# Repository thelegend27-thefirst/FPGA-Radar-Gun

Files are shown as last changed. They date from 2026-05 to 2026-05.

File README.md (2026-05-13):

# FPGA-Radar-Gun
FPGA Radar Gun project using a HB100 Doppler Radar Module 0~2mph

This project uses the HB100 Doppler Module to track speeds of different objects and displays it on the 7 segment display of the Nexys A7 FPGA board. To run the code simply clone the repo, open the xpr file, make sure top module is selected as top, and generate bitstream. After you have flashed the bitstream the Nexys A7 FPGA, build the circuit provided in the README system architecture section. You will need op-amps (I used MCP6002, but any op-amp works), resistors, and capacitors (electrolytic and ceramic). Connect the output of the circuit to JD1 of the FPGA. Also connect gnd of circuit to gnd of pmod JD. You can use the 3D printed chasis I have provided, though you will need double-sided tape for the HB100 to mount it and the FPGA board to make it stay still. 

# Project Overview
This project uses the HB100 Doppler Module. The module sends out radio waves and receives them. Due to the doppler effect, the radio waves sent back will have a shift in frequency. The module will output that change in frequency as an analog signal. The analog signal will then go through a circuit that will amplify it and convert it from analog to digital. It will then go into the FPGA board which will measure the frequency of the input signal and use a formula to calculate speed. The speed will be displayed on the 7 segment display. 

# System Architecture 

The output of the HB100 is a tiny analog signal (mV~uV) at a certain frequency. That frequency is the doppler effect frequency and exactly what we need to input into our formula. The output is so small and the FPGA can not read it. We will need to amplify it with a circuit. Here is how the circuit works. The analog signal first goes through a capacitor which filters out any DC offset from the HB100 because we only care about the AC part of the signal (1). Then we introduce a voltage divider to set a midpoint at 1.65v (3.3v/2). The midpoint is used because everything above the midpoint will be considered “high” and everything below will be “low” (2). After that our signal goes through a non-inveriting op amp which amplifies the signal 100x (3). Then a second non-inverting op amp turns the signal into a complete square wave (4). In the end we have a square wave at a frequency that is equivalent to the frequency of the doppler effect. Now we have to measure the frequency of the square wave which will be done inside the FPGA. 
Note: I did not end up use a decoupling capacitor on the HB100 as the vcc & gnd pins were too far apart

# Interfaces & Peripherals Used

To measure frequency the strategy I implemented was using a timer to count to the time between rising edges then using the formula f=1/T to measure frequency. I implemented a timer using the internal 100Mhz clk of the FPGA board. I used a loop so that at every posedge of the clk, I’d increment a counter by 1. This counter just counts. I then used another loop where at every posedge of the input signal, the counter would start, wait for the next posedge, stop, and output the count. Now what we have to do is multiply this count by .0000001 as each posedge of the clk is equal to .0000001s or 10 nano seconds. Then I divided 1 by the count to get frequency. However, this process simplifies to 100Mhz / count, so that is what I ended up using to get frequency. 

To convert frequency to speed the formula v=f*lamda/2. Lamda is the wavelength of the original wave, it is found using lamda=vf where v is equal to the speed of light. It varies across radar guns, our HB100 operates at 10.525 GHz and therefore lamda = .0285 in our case. A problem I faced was that the FPGA can not do floats so I had to modify the formula. I just ended up doing all the calculations with a decimal point over. For example a speed of 12.5 will be calculated as 125. Which is fine because we actually need it in this form for the 7 segment display later. The modified equation I used is v=(f  * 285) + 10002000. The +1000 is there because the FPGA always rounds down, so +1000 ensures proper rounding. I then used v=(v * 2237) + 5001000 to convert m/s to mph (m/s * 2.23694 = mph). It uses the same modifications as the first formula for the same reasons. Here is a table to show conversion from frequency to speed so you get an idea.

Frequency (Hz)     Speed (mph)
10                  0.32
20                  0.64
30                  0.96
1600                51.04

Once we had our speed we needed to display onto the 7 segment display. However the 7 segment display on the Nexys A7 FPGA board only has one set of cathodes connected to all 8 anodes. This means that one number will display on all of the 7 segments and you can’t send different numbers to different 7 segments. To display a 3 digit speed, I needed to implement multiplexing on the 7 segment display.  What we do is we take our first digit, turn off all the anodes except for one, and display that digit. Then we take the next digit, turn off all the anodes except for the next anode, and display the second digit. Same thing for the 3rd digit. The FPGA board does this so fast that it looks like all 3 digits are being displayed at the same time and you can see a clear speed. 

# Verification & Testing

For verification I did both software and hardware verification. For software verification I simulated different input frequencies being imputed into the FPGA board. I did it by creating a testbench and toggling the input at a fixed rate. To find how often I need to toggle, I would take the frequency I want to simulate input it into T=1f. This would give us the time for one period, then I would divide that by 2 to get the toggle delay. 

I noticed that during transitions, the FPGA would output speeds in between 2 frequencies. This is because it would read the rising edge of one frequency than read the rising edge of a different frequency, resulting in a speed in between. This was fine though as it just showed acceleration and deceleration. Note that speeds on waveform are 1 magnitude lower than displayed i.e. 320 = 32.0mph.

For hardware verification I did physical testing with the FPGA board, circuit, and module. I made all the connections using a breadboard and began rolling objects in front of the HB100. Something that I found really helpful was using an oscilloscope. The oscilloscope would display what’s happening with the signal and was very helpful with debugging. You can also see on the oscilloscope our circuit amplification as it takes a tiny signal in mV and amplifies it to a 3.3v square wave.





# Conclusion
In this project, I successfully designed and implemented an FPGA-based radar speedometer using the HB100 Doppler module. The system was able to detect motion, process the resulting Doppler frequency shift, and convert it into a readable speed displayed on a 7-segment display. This required integrating analog signal conditioning, digital frequency measurement, and hardware-based computation on the FPGA. Through both simulation and hardware testing, I verified that my design functioned as intended.
However, the overall performance of the system was limited by the HB100 module. The maximum output frequency observed was significantly lower than expected, restricting measurable speeds to approximately 0–2 mph. While the signal processing and FPGA implementation were correct, this hardware limitation prevented the system from being used for higher-speed applications such as vehicle detection.
In future work, this limitation could be addressed by selecting a Doppler module with a higher output frequency range or by improving the sensitivity and amplification stages of the circuit. Additionally, implementing more advanced signal processing techniques or filtering could improve accuracy and noise resilience. Despite its limitations, this project provided valuable experience in combining analog and digital design, working with real-world signals, and implementing mathematical models on FPGA hardware.



# Demos
https://www.youtube.com/watch?v=i8uyQCpuomU

https://www.youtube.com/watch?v=ts4kDAqrsdw

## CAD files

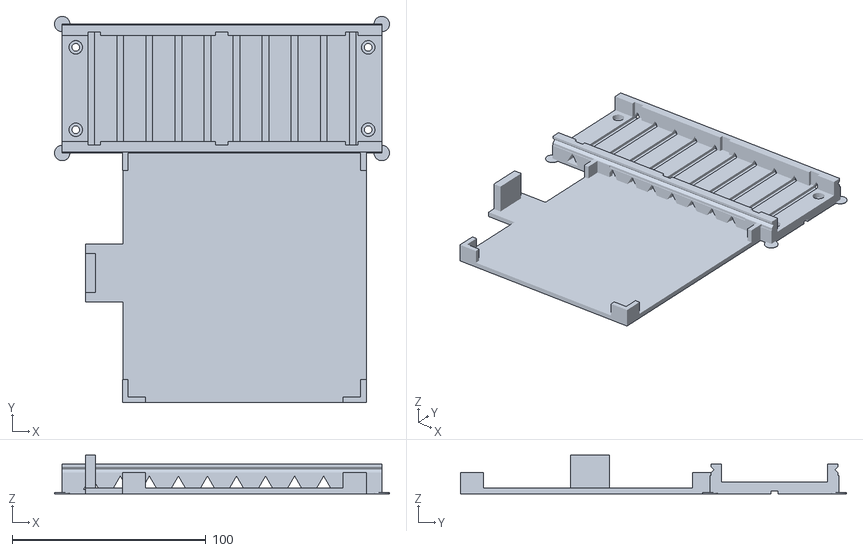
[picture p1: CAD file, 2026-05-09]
Nexys A7 FPGA & Breadboard (3).stl
173.1 x 199.6 x 20.0

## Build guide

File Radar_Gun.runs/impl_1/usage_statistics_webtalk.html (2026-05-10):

### Device Usage Page (usage_statistics_webtalk.html)

This HTML page displays the device usage statistics that will be sent to Xilinx.
To see the actual file transmitted to Xilinx, please click here.

software_version_and_target_device
beta | FALSE | build_version | 2708876
date_generated | Mon May 4 16:14:32 2026 | os_platform | WIN64
product_version | Vivado v2019.2 (64-bit) | project_id | d7756ef397354c6abce82c2c75414546
project_iteration | 7 | random_id | 1eeea3ededb85181a77914f9714619ef
registration_id | 1eeea3ededb85181a77914f9714619ef | route_design | TRUE
target_device | xc7a100t | target_family | artix7
target_package | csg324 | target_speed | -1
tool_flow | Vivado

user_environment
cpu_name | AMD Ryzen 7 7735HS with Radeon Graphics | cpu_speed | 3194 MHz
os_name | Windows Server 2016 or Windows 10 | os_release | major release (build 9200)
system_ram | 14.000 GB | total_processors | 1

vivado_usage

gui_handlers
addsrcwizard_specify_hdl_netlist_block_design=3 | addsrcwizard_specify_or_create_constraint_files=2 | addsrcwizard_specify_simulation_specific_hdl_files=1 | basedialog_cancel=11
basedialog_no=1 | basedialog_ok=46 | basedialog_yes=13 | closeplanner_no=1
cmdmsgdialog_ok=22 | commandsinput_type_tcl_command_here=1 | constraintschooserpanel_add_files=1 | constraintschooserpanel_create_file=3
constraintschooserpanel_file_table=1 | createconstraintsfilepanel_file_name=2 | createsrcfiledialog_file_name=8 | filesetpanel_file_set_panel_tree=228
flownavigatortreepanel_flow_navigator_tree=106 | graphicalview_zoom_fit=39 | hcodeeditor_search_text_combo_box=2 | logmonitor_monitor=1
logpanel_pause_output=4 | mainmenumgr_file=6 | mainmenumgr_project=6 | msgtreepanel_message_view_tree=18
pacommandnames_add_sources=11 | pacommandnames_auto_connect_target=6 | pacommandnames_auto_update_hier=45 | pacommandnames_edit_constraint_sets=1
pacommandnames_edit_simulation_sets=1 | pacommandnames_make_active_cnsset=6 | pacommandnames_open_hardware_manager=2 | pacommandnames_open_project=3
pacommandnames_set_as_top=7 | pacommandnames_set_target_ucf=4 | pacommandnames_set_used_in_prop=1 | pacommandnames_simulation_live_run_all=20
pacommandnames_simulation_run_behavioral=36 | pacommandnames_src_disable=3 | pacommandnames_src_enable=1 | paviews_code=4
paviews_project_summary=42 | paviews_schematic=1 | programdebugtab_open_target=7 | programdebugtab_program_device=12
programfpgadialog_program=16 | programfpgadialog_specify_bitstream_file=1 | rdicommands_copy=1 | rdicommands_delete=2
rdicommands_properties=1 | rdicommands_redo=4 | rdicommands_undo=9 | rdiviews_waveform_viewer=170
saveprojectutils_cancel=1 | saveprojectutils_dont_save=1 | saveprojectutils_save=2 | srcchooserpanel_create_file=8
srcfileproppanels_enabled=1 | srcmenu_ip_hierarchy=48 | srcmenu_refresh_hierarchy=1 | srcmenu_set_file_type=3
syntheticagettingstartedview_recent_projects=3 | taskbanner_close=1 | waveformnametree_waveform_name_tree=68 | waveformview_add_marker=3
waveformview_goto_cursor=13 | waveformview_goto_last_time=4 | waveformview_goto_time_0=1 | waveformview_next_marker=2
waveformview_next_transition=5 | waveformview_previous_marker=1

java_command_handlers
addsources=11 | autoconnecttarget=6 | editconstraintsets=1 | editdelete=2
editproperties=1 | editsimulationsets=1 | launchprogramfpga=14 | openhardwaremanager=6
openproject=3 | programdevice=2 | runbitgen=16 | runimplementation=1
runschematic=1 | savefileproxyhandler=2 | setsourceenabled=5 | settargetconstrfile=2
settopnode=6 | showview=7 | simulationrun=35 | simulationrunall=20
viewtaskimplementation=1 | viewtaskprojectmanager=19

other_data

guimode=12

project_data
constraintsetcount=2 | core_container=false | currentimplrun=impl_1 | currentsynthesisrun=synth_1
default_library=xil_defaultlib | designmode=RTL | export_simulation_activehdl=0 | export_simulation_ies=0
export_simulation_modelsim=0 | export_simulation_questa=0 | export_simulation_riviera=0 | export_simulation_vcs=0
export_simulation_xsim=0 | implstrategy=Vivado Implementation Defaults | launch_simulation_activehdl=0 | launch_simulation_ies=0
launch_simulation_modelsim=0 | launch_simulation_questa=0 | launch_simulation_riviera=0 | launch_simulation_vcs=0
launch_simulation_xsim=57 | simulator_language=Mixed | srcsetcount=6 | synthesisstrategy=Vivado Synthesis Defaults
target_language=Verilog | target_simulator=XSim | totalimplruns=1 | totalsynthesisruns=1

unisim_transformation

post_unisim_transformation
bufg=1 | carry4=304 | dsp48e1=2 | fdce=65
fdre=17 | gnd=4 | ibuf=3 | lut1=70
lut2=139 | lut3=924 | lut4=60 | lut5=53
lut6=105 | obuf=16 | vcc=3

pre_unisim_transformation
bufg=1 | carry4=304 | dsp48e1=2 | fdce=65
fdre=17 | gnd=4 | ibuf=3 | lut1=70
lut2=139 | lut3=924 | lut4=60 | lut5=53
lut6=105 | obuf=16 | vcc=3

phys_opt_design_post_place

command_line_options
-aggressive_hold_fix=default::[not_specified] | -bram_register_opt=default::[not_specified] | -clock_opt=default::[not_specified] | -critical_cell_opt=default::[not_specified]
-critical_pin_opt=default::[not_specified] | -directive=default::[not_specified] | -dsp_register_opt=default::[not_specified] | -effort_level=default::[not_specified]
-fanout_opt=default::[not_specified] | -hold_fix=default::[not_specified] | -insert_negative_edge_ffs=default::[not_specified] | -multi_clock_opt=default::[not_specified]
-placement_opt=default::[not_specified] | -restruct_opt=default::[not_specified] | -retime=default::[not_specified] | -rewire=default::[not_specified]
-shift_register_opt=default::[not_specified] | -uram_register_opt=default::[not_specified] | -verbose=default::[not_specified] | -vhfn=default::[not_specified]

report_drc

command_line_options
-append=default::[not_specified] | -checks=default::[not_specified] | -fail_on=default::[not_specified] | -force=default::[not_specified]
-format=default::[not_specified] | -internal=default::[not_specified] | -internal_only=default::[not_specified] | -messages=default::[not_specified]
-name=default::[not_specified] | -no_waivers=default::[not_specified] | -return_string=default::[not_specified] | -ruledecks=default::[not_specified]
-upgrade_cw=default::[not_specified] | -waived=default::[not_specified]

results
cfgbvs-1=1 | dpip-1=2 | dpop-1=2 | dpop-2=2

report_methodology

command_line_options
-append=default::[not_specified] | -checks=default::[not_specified] | -fail_on=default::[not_specified] | -force=default::[not_specified]
-format=default::[not_specified] | -messages=default::[not_specified] | -name=default::[not_specified] | -return_string=default::[not_specified]
-slack_lesser_than=default::[not_specified] | -waived=default::[not_specified]

results

timing-18=18

report_power

command_line_options
-advisory=default::[not_specified] | -append=default::[not_specified] | -file=[specified] | -format=default::text
-hier=default::power | -hierarchical_depth=default::4 | -l=default::[not_specified] | -name=default::[not_specified]
-no_propagation=default::[not_specified] | -return_string=default::[not_specified] | -rpx=[specified] | -verbose=default::[not_specified]
-vid=default::[not_specified] | -xpe=default::[not_specified]

usage
airflow=250 (LFM) | ambient_temp=25.0 (C) | bi-dir_toggle=12.500000 | bidir_output_enable=1.000000
board_layers=12to15 (12 to 15 Layers) | board_selection=medium (10"x10") | clocks=0.000883 | confidence_level_clock_activity=High
confidence_level_design_state=High | confidence_level_device_models=High | confidence_level_internal_activity=Medium | confidence_level_io_activity=Medium
confidence_level_overall=Medium | customer=TBD | customer_class=TBD | devstatic=0.097227
die=xc7a100tcsg324-1 | dsp=0.002078 | dsp_output_toggle=12.500000 | dynamic=0.052287
effective_thetaja=4.6 | enable_probability=0.990000 | family=artix7 | ff_toggle=12.500000
flow_state=routed | heatsink=medium (Medium Profile) | i/o=0.018981 | input_toggle=12.500000
junction_temp=25.7 (C) | logic=0.016251 | mgtavcc_dynamic_current=0.000000 | mgtavcc_static_current=0.000000
mgtavcc_total_current=0.000000 | mgtavcc_voltage=1.000000 | mgtavtt_dynamic_current=0.000000 | mgtavtt_static_current=0.000000
mgtavtt_total_current=0.000000 | mgtavtt_voltage=1.200000 | netlist_net_matched=NA | off-chip_power=0.000000
on-chip_power=0.149515 | output_enable=1.000000 | output_load=5.000000 | output_toggle=12.500000
package=csg324 | pct_clock_constrained=2.000000 | pct_inputs_defined=33 | platform=nt64
process=typical | ram_enable=50.000000 | ram_write=50.000000 | read_saif=False
set/reset_probability=0.000000 | signal_rate=False | signals=0.014094 | simulation_file=None
speedgrade=-1 | static_prob=False | temp_grade=commercial | thetajb=5.7 (C/W)
thetasa=4.6 (C/W) | toggle_rate=False | user_board_temp=25.0 (C) | user_effective_thetaja=4.6
user_junc_temp=25.7 (C) | user_thetajb=5.7 (C/W) | user_thetasa=4.6 (C/W) | vccadc_dynamic_current=0.000000
vccadc_static_current=0.020000 | vccadc_total_current=0.020000 | vccadc_voltage=1.800000 | vccaux_dynamic_current=0.000693
vccaux_io_dynamic_current=0.000000 | vccaux_io_static_current=0.000000 | vccaux_io_total_current=0.000000 | vccaux_io_voltage=1.800000
vccaux_static_current=0.018150 | vccaux_total_current=0.018843 | vccaux_voltage=1.800000 | vccbram_dynamic_current=0.000000
vccbram_static_current=0.000247 | vccbram_total_current=0.000247 | vccbram_voltage=1.000000 | vccint_dynamic_current=0.033374
vccint_static_current=0.015109 | vccint_total_current=0.048484 | vccint_voltage=1.000000 | vcco12_dynamic_current=0.000000
vcco12_static_current=0.000000 | vcco12_total_current=0.000000 | vcco12_voltage=1.200000 | vcco135_dynamic_current=0.000000
vcco135_static_current=0.000000 | vcco135_total_current=0.000000 | vcco135_voltage=1.350000 | vcco15_dynamic_current=0.000000
vcco15_static_current=0.000000 | vcco15_total_current=0.000000 | vcco15_voltage=1.500000 | vcco18_dynamic_current=0.000000
vcco18_static_current=0.000000 | vcco18_total_current=0.000000 | vcco18_voltage=1.800000 | vcco25_dynamic_current=0.000000
vcco25_static_current=0.000000 | vcco25_total_current=0.000000 | vcco25_voltage=2.500000 | vcco33_dynamic_current=0.005353
vcco33_static_current=0.004000 | vcco33_total_current=0.009353 | vcco33_voltage=3.300000 | version=2019.2

report_utilization

clocking
bufgctrl_available=32 | bufgctrl_fixed=0 | bufgctrl_used=1 | bufgctrl_util_percentage=3.13
bufhce_available=96 | bufhce_fixed=0 | bufhce_used=0 | bufhce_util_percentage=0.00
bufio_available=24 | bufio_fixed=0 | bufio_used=0 | bufio_util_percentage=0.00
bufmrce_available=12 | bufmrce_fixed=0 | bufmrce_used=0 | bufmrce_util_percentage=0.00
bufr_available=24 | bufr_fixed=0 | bufr_used=0 | bufr_util_percentage=0.00
mmcme2_adv_available=6 | mmcme2_adv_fixed=0 | mmcme2_adv_used=0 | mmcme2_adv_util_percentage=0.00
plle2_adv_available=6 | plle2_adv_fixed=0 | plle2_adv_used=0 | plle2_adv_util_percentage=0.00

dsp
dsp48e1_only_used=2 | dsps_available=240 | dsps_fixed=0 | dsps_used=2

dsps_util_percentage=0.83

io_standard
blvds_25=0 | diff_hstl_i=0 | diff_hstl_i_18=0 | diff_hstl_ii=0
diff_hstl_ii_18=0 | diff_hsul_12=0 | diff_mobile_ddr=0 | diff_sstl135=0
diff_sstl135_r=0 | diff_sstl15=0 | diff_sstl15_r=0 | diff_sstl18_i=0
diff_sstl18_ii=0 | hstl_i=0 | hstl_i_18=0 | hstl_ii=0
hstl_ii_18=0 | hsul_12=0 | lvcmos12=0 | lvcmos15=0
lvcmos18=0 | lvcmos25=0 | lvcmos33=1 | lvds_25=0
lvttl=0 | mini_lvds_25=0 | mobile_ddr=0 | pci33_3=0
ppds_25=0 | rsds_25=0 | sstl135=0 | sstl135_r=0
sstl15=0 | sstl15_r=0 | sstl18_i=0 | sstl18_ii=0

tmds_33=0

memory
block_ram_tile_available=135 | block_ram_tile_fixed=0 | block_ram_tile_used=0 | block_ram_tile_util_percentage=0.00
ramb18_available=270 | ramb18_fixed=0 | ramb18_used=0 | ramb18_util_percentage=0.00
ramb36_fifo_available=135 | ramb36_fifo_fixed=0 | ramb36_fifo_used=0 | ramb36_fifo_util_percentage=0.00

primitives
bufg_functional_category=Clock | bufg_used=1 | carry4_functional_category=CarryLogic | carry4_used=304
dsp48e1_functional_category=Block Arithmetic | dsp48e1_used=2 | fdce_functional_category=Flop & Latch | fdce_used=65
fdre_functional_category=Flop & Latch | fdre_used=17 | ibuf_functional_category=IO | ibuf_used=3
lut1_functional_category=LUT | lut1_used=70 | lut2_functional_category=LUT | lut2_used=139
lut3_functional_category=LUT | lut3_used=924 | lut4_functional_category=LUT | lut4_used=60
lut5_functional_category=LUT | lut5_used=53 | lut6_functional_category=LUT | lut6_used=105
obuf_functional_category=IO | obuf_used=16

slice_logic
f7_muxes_available=31700 | f7_muxes_fixed=0 | f7_muxes_used=0 | f7_muxes_util_percentage=0.00
f8_muxes_available=15850 | f8_muxes_fixed=0 | f8_muxes_used=0 | f8_muxes_util_percentage=0.00
lut_as_logic_available=63400 | lut_as_logic_fixed=0 | lut_as_logic_used=1202 | lut_as_logic_util_percentage=1.90
lut_as_memory_available=19000 | lut_as_memory_fixed=0 | lut_as_memory_used=0 | lut_as_memory_util_percentage=0.00
register_as_flip_flop_available=126800 | register_as_flip_flop_fixed=0 | register_as_flip_flop_used=82 | register_as_flip_flop_util_percentage=0.06
register_as_latch_available=126800 | register_as_latch_fixed=0 | register_as_latch_used=0 | register_as_latch_util_percentage=0.00
slice_luts_available=63400 | slice_luts_fixed=0 | slice_luts_used=1202 | slice_luts_util_percentage=1.90
slice_registers_available=126800 | slice_registers_fixed=0 | slice_registers_used=82 | slice_registers_util_percentage=0.06
lut_as_distributed_ram_fixed=0 | lut_as_distributed_ram_used=0 | lut_as_logic_available=63400 | lut_as_logic_fixed=0
lut_as_logic_used=1202 | lut_as_logic_util_percentage=1.90 | lut_as_memory_available=19000 | lut_as_memory_fixed=0
lut_as_memory_used=0 | lut_as_memory_util_percentage=0.00 | lut_as_shift_register_fixed=0 | lut_as_shift_register_used=0
lut_in_front_of_the_register_is_unused_fixed=0 | lut_in_front_of_the_register_is_unused_used=8 | lut_in_front_of_the_register_is_used_fixed=8 | lut_in_front_of_the_register_is_used_used=25
register_driven_from_outside_the_slice_fixed=25 | register_driven_from_outside_the_slice_used=33 | register_driven_from_within_the_slice_fixed=33 | register_driven_from_within_the_slice_used=49
slice_available=15850 | slice_fixed=0 | slice_registers_available=126800 | slice_registers_fixed=0
slice_registers_used=82 | slice_registers_util_percentage=0.06 | slice_used=339 | slice_util_percentage=2.14
slicel_fixed=0 | slicel_used=207 | slicem_fixed=0 | slicem_used=132
unique_control_sets_available=15850 | unique_control_sets_fixed=15850 | unique_control_sets_used=3 | unique_control_sets_util_percentage=0.02
using_o5_and_o6_fixed=0.02 | using_o5_and_o6_used=149 | using_o5_output_only_fixed=149 | using_o5_output_only_used=1
using_o6_output_only_fixed=1 | using_o6_output_only_used=1052

specific_feature
bscane2_available=4 | bscane2_fixed=0 | bscane2_used=0 | bscane2_util_percentage=0.00
capturee2_available=1 | capturee2_fixed=0 | capturee2_used=0 | capturee2_util_percentage=0.00
dna_port_available=1 | dna_port_fixed=0 | dna_port_used=0 | dna_port_util_percentage=0.00
efuse_usr_available=1 | efuse_usr_fixed=0 | efuse_usr_used=0 | efuse_usr_util_percentage=0.00
frame_ecce2_available=1 | frame_ecce2_fixed=0 | frame_ecce2_used=0 | frame_ecce2_util_percentage=0.00
icape2_available=2 | icape2_fixed=0 | icape2_used=0 | icape2_util_percentage=0.00
pcie_2_1_available=1 | pcie_2_1_fixed=0 | pcie_2_1_used=0 | pcie_2_1_util_percentage=0.00
startupe2_available=1 | startupe2_fixed=0 | startupe2_used=0 | startupe2_util_percentage=0.00
xadc_available=1 | xadc_fixed=0 | xadc_used=0 | xadc_util_percentage=0.00

synthesis

command_line_options
-assert=default::[not_specified] | -bufg=default::12 | -cascade_dsp=default::auto | -constrset=default::[not_specified]
-control_set_opt_threshold=default::auto | -directive=default::default | -fanout_limit=default::10000 | -flatten_hierarchy=default::rebuilt
-fsm_extraction=default::auto | -gated_clock_conversion=default::off | -generic=default::[not_specified] | -include_dirs=default::[not_specified]
-keep_equivalent_registers=default::[not_specified] | -max_bram=default::-1 | -max_bram_cascade_height=default::-1 | -max_dsp=default::-1
-max_uram=default::-1 | -max_uram_cascade_height=default::-1 | -mode=default::default | -name=default::[not_specified]
-no_lc=default::[not_specified] | -no_srlextract=default::[not_specified] | -no_timing_driven=default::[not_specified] | -part=xc7a100tcsg324-1
-resource_sharing=default::auto | -retiming=default::[not_specified] | -rtl=default::[not_specified] | -rtl_skip_constraints=default::[not_specified]
-rtl_skip_ip=default::[not_specified] | -seu_protect=default::none | -sfcu=default::[not_specified] | -shreg_min_size=default::3
-top=top | -verilog_define=default::[not_specified]

usage
elapsed=00:00:50s | hls_ip=0 | memory_gain=793.066MB | memory_peak=1124.848MB

xsim

command_line_options
-sim_mode=default::behavioral | -sim_type=default::

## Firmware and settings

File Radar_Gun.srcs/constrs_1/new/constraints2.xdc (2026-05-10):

## This file is a general .xdc for the Nexys A7-100T
## To use it in a project:
## - uncomment the lines corresponding to used pins
## - rename the used ports (in each line, after get_ports) according to the top level signal names in the project

## Clock signal
#set_property -dict { PACKAGE_PIN E3    IOSTANDARD LVCMOS33 } [get_ports { CLK100MHZ }]; #IO_L12P_T1_MRCC_35 Sch=clk100mhz
#create_clock -add -name sys_clk_pin -period 10.00 -waveform {0 5} [get_ports {CLK100MHZ}];
set_property -dict { PACKAGE_PIN E3    IOSTANDARD LVCMOS33 } [get_ports { clk }]; #IO_L12P_T1_MRCC_35 Sch=clk100mhz
create_clock -add -name clk -period 10.00 -waveform {0 5} [get_ports {clk}];

##Switches
#set_property -dict { PACKAGE_PIN J15   IOSTANDARD LVCMOS33 } [get_ports { num[0] }]; #IO_L24N_T3_RS0_15 Sch=sw[0]
#set_property -dict { PACKAGE_PIN L16   IOSTANDARD LVCMOS33 } [get_ports { num[1] }]; #IO_L3N_T0_DQS_EMCCLK_14 Sch=sw[1]
#set_property -dict { PACKAGE_PIN M13   IOSTANDARD LVCMOS33 } [get_ports { num[2] }]; #IO_L6N_T0_D08_VREF_14 Sch=sw[2]
#set_property -dict { PACKAGE_PIN R15   IOSTANDARD LVCMOS33 } [get_ports { num[3] }]; #IO_L13N_T2_MRCC_14 Sch=sw[3]
#set_property -dict { PACKAGE_PIN R17   IOSTANDARD LVCMOS33 } [get_ports { SW[4] }]; #IO_L12N_T1_MRCC_14 Sch=sw[4]
#set_property -dict { PACKAGE_PIN T18   IOSTANDARD LVCMOS33 } [get_ports { SW[5] }]; #IO_L7N_T1_D10_14 Sch=sw[5]
#set_property -dict { PACKAGE_PIN U18   IOSTANDARD LVCMOS33 } [get_ports { SW[6] }]; #IO_L17N_T2_A13_D29_14 Sch=sw[6]
#set_property -dict { PACKAGE_PIN R13   IOSTANDARD LVCMOS33 } [get_ports { SW[7] }]; #IO_L5N_T0_D07_14 Sch=sw[7]
#set_property -dict { PACKAGE_PIN T8    IOSTANDARD LVCMOS18 } [get_ports { SW[8] }]; #IO_L24N_T3_34 Sch=sw[8]
#set_property -dict { PACKAGE_PIN U8    IOSTANDARD LVCMOS18 } [get_ports { SW[9] }]; #IO_25_34 Sch=sw[9]
#set_property -dict { PACKAGE_PIN R16   IOSTANDARD LVCMOS33 } [get_ports { SW[10] }]; #IO_L15P_T2_DQS_RDWR_B_14 Sch=sw[10]
#set_property -dict { PACKAGE_PIN T13   IOSTANDARD LVCMOS33 } [get_ports { SW[11] }]; #IO_L23P_T3_A03_D19_14 Sch=sw[11]
#set_property -dict { PACKAGE_PIN H6    IOSTANDARD LVCMOS33 } [get_ports { SW[12] }]; #IO_L24P_T3_35 Sch=sw[12]
#set_property -dict { PACKAGE_PIN U12   IOSTANDARD LVCMOS33 } [get_ports { SW[13] }]; #IO_L20P_T3_A08_D24_14 Sch=sw[13]
#set_property -dict { PACKAGE_PIN U11   IOSTANDARD LVCMOS33 } [get_ports { SW[14] }]; #IO_L19N_T3_A09_D25_VREF_14 Sch=sw[14]
#set_property -dict { PACKAGE_PIN V10   IOSTANDARD LVCMOS33 } [get_ports { SW[15] }]; #IO_L21P_T3_DQS_14 Sch=sw[15]

## LEDs
#set_property -dict { PACKAGE_PIN H17   IOSTANDARD LVCMOS33 } [get_ports { out[0] }]; #IO_L18P_T2_A24_15 Sch=led[0]
#set_property -dict { PACKAGE_PIN K15   IOSTANDARD LVCMOS33 } [get_ports { out[1] }]; #IO_L24P_T3_RS1_15 Sch=led[1]
#set_property -dict { PACKAGE_PIN J13   IOSTANDARD LVCMOS33 } [get_ports { out[2] }]; #IO_L17N_T2_A25_15 Sch=led[2]
#set_property -dict { PACKAGE_PIN N14   IOSTANDARD LVCMOS33 } [get_ports { out[3] }]; #IO_L8P_T1_D11_14 Sch=led[3]
#set_property -dict { PACKAGE_PIN R18   IOSTANDARD LVCMOS33 } [get_ports { out[4] }]; #IO_L7P_T1_D09_14 Sch=led[4]
#set_property -dict { PACKAGE_PIN V17   IOSTANDARD LVCMOS33 } [get_ports { out[5] }]; #IO_L18N_T2_A11_D27_14 Sch=led[5]
#set_property -dict { PACKAGE_PIN U17   IOSTANDARD LVCMOS33 } [get_ports { out[6] }]; #IO_L17P_T2_A14_D30_14 Sch=led[6]
#set_property -dict { PACKAGE_PIN U16   IOSTANDARD LVCMOS33 } [get_ports { out[7] }]; #IO_L18P_T2_A12_D28_14 Sch=led[7]
#set_property -dict { PACKAGE_PIN V16   IOSTANDARD LVCMOS33 } [get_ports { out[8] }]; #IO_L16N_T2_A15_D31_14 Sch=led[8]
#set_property -dict { PACKAGE_PIN T15   IOSTANDARD LVCMOS33 } [get_ports { out[9] }]; #IO_L14N_T2_SRCC_14 Sch=led[9]
#set_property -dict { PACKAGE_PIN U14   IOSTANDARD LVCMOS33 } [get_ports { out[10] }]; #IO_L22P_T3_A05_D21_14 Sch=led[10]
#set_property -dict { PACKAGE_PIN T16   IOSTANDARD LVCMOS33 } [get_ports { out[11] }]; #IO_L15N_T2_DQS_DOUT_CSO_B_14 Sch=led[11]
#set_property -dict { PACKAGE_PIN V15   IOSTANDARD LVCMOS33 } [get_ports { out[12] }]; #IO_L16P_T2_CSI_B_14 Sch=led[12]
#set_property -dict { PACKAGE_PIN V14   IOSTANDARD LVCMOS33 } [get_ports { out[13] }]; #IO_L22N_T3_A04_D20_14 Sch=led[13]
#set_property -dict { PACKAGE_PIN V12   IOSTANDARD LVCMOS33 } [get_ports { out[14] }]; #IO_L20N_T3_A07_D23_14 Sch=led[14]
#set_property -dict { PACKAGE_PIN V11   IOSTANDARD LVCMOS33 } [get_ports { out[15] }]; #IO_L21N_T3_DQS_A06_D22_14 Sch=led[15]
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

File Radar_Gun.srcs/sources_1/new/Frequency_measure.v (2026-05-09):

`timescale 1ns / 1ps
//////////////////////////////////////////////////////////////////////////////////
// Company: 
// Engineer: 
// 
// Create Date: 04/26/2026 11:05:42 PM
// Design Name: 
// Module Name: Frequency_measure
// Project Name: 
// Target Devices: 
// Tool Versions: 
// Description: 
// 
// Dependencies: 
// 
// Revision:
// Revision 0.01 - File Created
// Additional Comments:
// 
//////////////////////////////////////////////////////////////////////////////////


module Frequency_measure (
    input  wire CLK100MHZ,
    input  wire radar_in,          // CLEAN digital square wave from comparator/Schmitt trigger
    input  wire resetn,            // active-low reset
    output reg  [7:0] AN,          // active-low digit enables
    output reg  CA, CB, CC, CD, CE, CF, CG, DP
);

    // ============================================================
    // Parameters
    // ============================================================
    localparam integer CLK_HZ            = 100_000_000;
    localparam integer HALF_SEC_TICKS    = 50_000_000;

    // HB100 at 10.525 GHz:
    // fd = 31.36 * mph
    // mph_tenths = (freq_hz * 10) / 31.36
    //            = (freq_hz * 1000) / 3136
    // freq_hz    = CLK_HZ / period_cycles
    //
    // So:
    // mph_tenths = (CLK_HZ * 1000) / (3136 * period_cycles)
    //
    // For 100 MHz clock:
    localparam integer MPH10_NUM         = 31_887_755; // approx (100_000_000*1000)/3136

    // Reject absurdly high values/noise
    localparam integer MAX_MPH10_VALID   = 9999;       // 999.9 mph max shown/accepted

    // ============================================================
    // Synchronize radar input into FPGA clock domain
    // ============================================================
    reg radar_ff1, radar_ff2, radar_ff3;

    always @(posedge CLK100MHZ) begin
        radar_ff1 <= radar_in;
        radar_ff2 <= radar_ff1;
        radar_ff3 <= radar_ff2;
    end

    wire radar_rise = (radar_ff2 == 1'b1) && (radar_ff3 == 1'b0);

    // ============================================================
    // Period measurement
    // ============================================================
    reg [31:0] cycle_counter = 0;
    reg [31:0] last_period   = 0;
    reg        period_valid  = 0;

    always @(posedge CLK100MHZ) begin
        if (!resetn) begin
            cycle_counter <= 0;
            last_period   <= 0;
            period_valid  <= 0;
        end else begin
            cycle_counter <= cycle_counter + 1;

            if (radar_rise) begin
                last_period   <= cycle_counter;
                cycle_counter <= 0;
                period_valid  <= (cycle_counter != 0);
            end
        end
    end

    // ============================================================
    // Convert one period reading into mph*10
    // ============================================================
    reg [31:0] mph10_now;

    always @(*) begin
        if (last_period != 0)
            mph10_now = MPH10_NUM / last_period;
        else
            mph10_now = 0;
    end

    // ============================================================
    // Half-second averaging
    // ============================================================
    reg [25:0] halfsec_counter = 0;

    reg [47:0] speed_sum   = 0;   // enough headroom
    reg [15:0] speed_count = 0;

    reg [31:0] avg_mph10   = 0;   // displayed value, mph*10

    always @(posedge CLK100MHZ) begin
        if (!resetn) begin
            halfsec_counter <= 0;
            speed_sum       <= 0;
            speed_count     <= 0;
            avg_mph10       <= 0;
        end else begin
            // accumulate valid readings on each new measured period
            if (radar_rise && period_valid) begin
                if ((mph10_now > 0) && (mph10_now <= MAX_MPH10_VALID)) begin
                    speed_sum   <= speed_sum + mph10_now;
                    speed_count <= speed_count + 1;
                end
            end

            // 0.5 second update
            if (halfsec_counter == HALF_SEC_TICKS - 1) begin
                halfsec_counter <= 0;

                if (speed_count != 0)
                    avg_mph10 <= speed_sum / speed_count;
                else
                    avg_mph10 <= 0;

                speed_sum   <= 0;
                speed_count <= 0;
            end else begin
                halfsec_counter <= halfsec_counter + 1;
            end
        end
    end

    // ============================================================
    // Convert avg_mph10 to 4 display digits: XXX.X
    // ============================================================
    reg [3:0] digit3, digit2, digit1, digit0; // digit0 is tenths

    integer temp;
    always @(*) begin
        temp   = avg_mph10;
        digit0 = temp % 10;       // tenths
        temp   = temp / 10;
        digit1 = temp % 10;       // ones
        temp   = temp / 10;
        digit2 = temp % 10;       // tens
        temp   = temp / 10;
        digit3 = temp % 10;       // hundreds
    end

    // ============================================================
    // 7-segment scan
    // Show on rightmost 4 digits, blank upper 4 digits
    // Active-low segments and anodes on Nexys A7
    // ============================================================
    reg [19:0] scan_counter = 0;
    always @(posedge CLK100MHZ) begin
        scan_counter <= scan_counter + 1;
    end

    wire [2:0] scan_sel = scan_counter[19:17];

    reg [3:0] seg_value;
    reg       seg_dp;
    reg [6:0] seg7;

    // Hex/decimal to 7-seg, active-low abcdefg
    always @(*) begin
        case (seg_value)
            4'd0: seg7 = 7'b0000001;
            4'd1: seg7 = 7'b1001111;
            4'd2: seg7 = 7'b0010010;
            4'd3: seg7 = 7'b0000110;
            4'd4: seg7 = 7'b1001100;
            4'd5: seg7 = 7'b0100100;
            4'd6: seg7 = 7'b0100000;
            4'd7: seg7 = 7'b0001111;
            4'd8: seg7 = 7'b0000000;
            4'd9: seg7 = 7'b0000100;
            default: seg7 = 7'b1111111; // blank
        endcase
    end

    always @(*) begin
        // defaults: everything off
        AN       = 8'b11111111;
        seg_value = 4'hF;       // blank
        seg_dp    = 1'b1;       // dp off (active-low)
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

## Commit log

2026-05-09 Add files via upload
    3d print
    [Nexys A7 FPGA & Breadboard (3).stl]
2026-05-10 Name change
    Doesn't work if name isn't "constraints2.xdc"
    [constraints2.xdc]
